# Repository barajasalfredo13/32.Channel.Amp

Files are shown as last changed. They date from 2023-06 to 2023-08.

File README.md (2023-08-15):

# 32.Channel.Amp
  
-----------------  
## Table of Contents
- 🔲 [Tile Boards]   
  - [Digi-Key Component List]
  - [Schematic]  
  - [Test Board]  
  - [Cell Board]  
- 🔲 [32 Cell Channel Receiver Board]  
  - [Cell Receiver Board]
  - [Cell Tester]
- 🔲 [Resources]  
  - [ Board Reference ]  
  - [ Amp Details ]  
  - [ Expected Connector ]  
  - [ Connections ]

----------------
## 🔲 ::: Tile Boards :::   
### : Component List :  
: Diodes :  
[ 1N4148W ](https://www.digikey.com/en/products/detail/smc-diode-solutions/1N4148W/6022450)  
[ BZT52H-A7V5-QX ](https://www.digikey.com/en/products/detail/nexperia-usa-inc/BZT52H-A7V5-QX/17295939)  
: Transistors :  
[ MMBT3904 ](https://www.digikey.com/en/products/detail/anbon-semiconductor-int-l-limited/MMBT3904/17284363)  
[ MMBT3906 ](https://www.digikey.com/en/products/detail/nte-electronics-inc/MMBT3906/11652283)  
: Capacitor :  
[ GRM188C81C106MA73J ](https://www.digikey.com/en/products/detail/murata-electronics/GRM188C81C106MA73J/4905316)  
: Resistors :  
[ RC0402JR-071KL ](https://www.digikey.com/en/products/detail/yageo/RC0402JR-071KL/726408)  
[ 311-4.7GRCT-ND ](https://www.digikey.com/en/products/detail/yageo/RC0603JR-074R7L/726784)  
: Cremat Holder :   
[ SMC-1-08-1-GT ](https://www.digikey.com/en/products/detail/adam-tech/SMC-1-08-1-GT/9830825)  
: DSUB Connector :  
[50 D-Sub](https://www.digikey.com/en/products/detail/harting/09665627811/4322749)  
[9 D-Sub](https://www.digikey.com/en/products/detail/te-connectivity-amp-connectors/2311765-1/7794751)  

### : Schematic :  
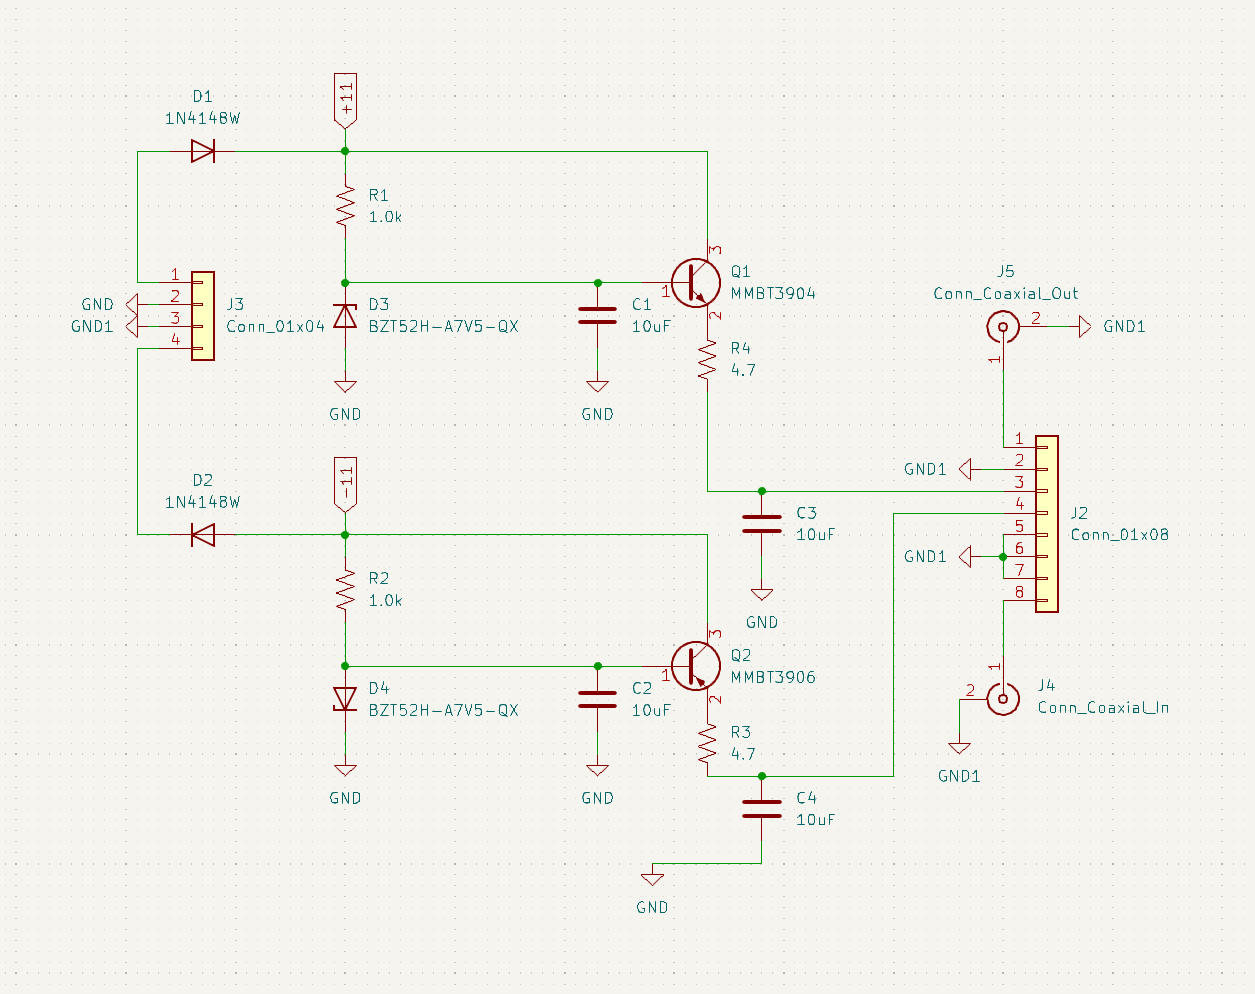
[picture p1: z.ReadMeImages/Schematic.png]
  
  
### :: Test Board ::  
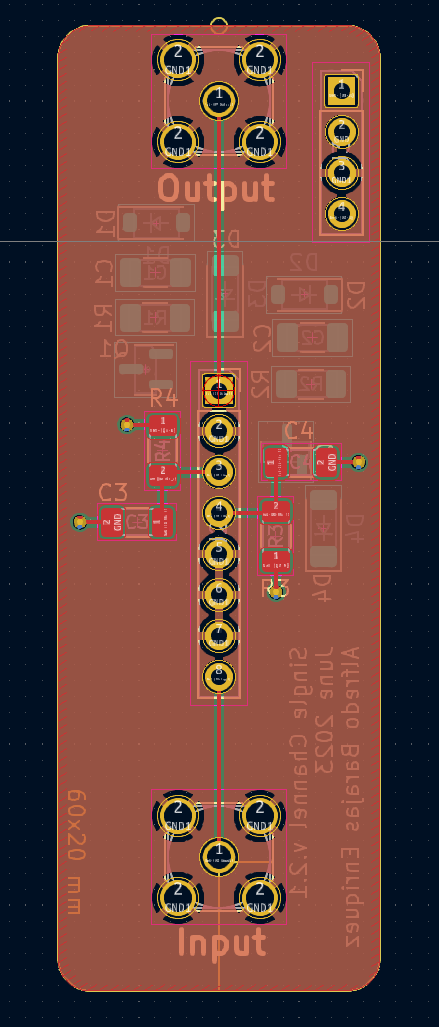
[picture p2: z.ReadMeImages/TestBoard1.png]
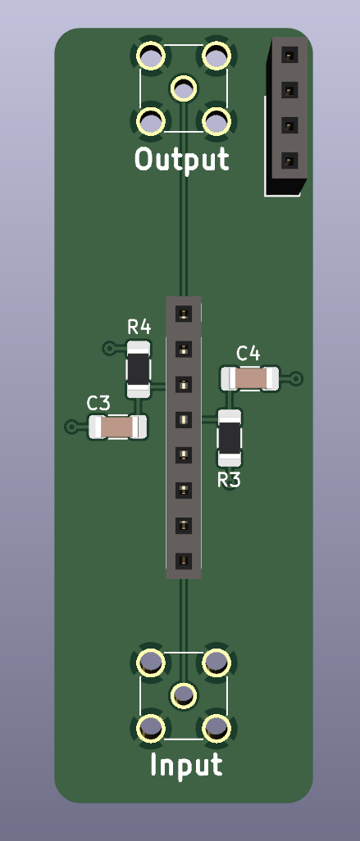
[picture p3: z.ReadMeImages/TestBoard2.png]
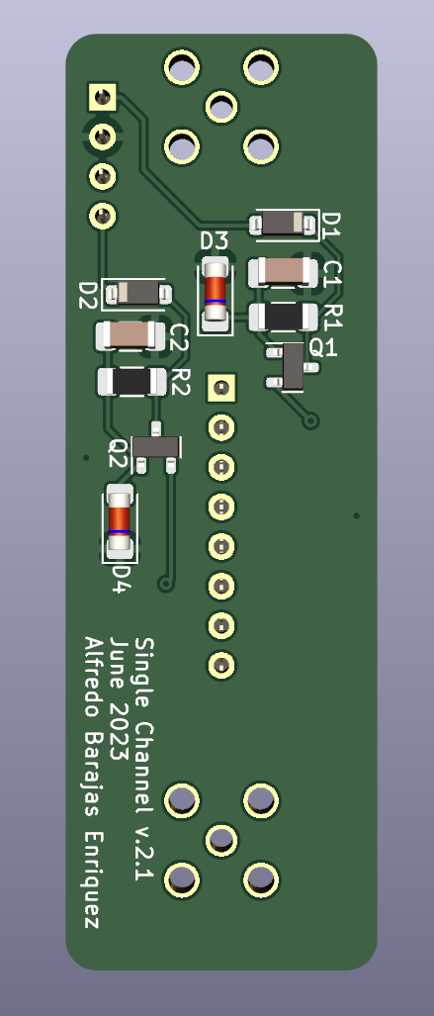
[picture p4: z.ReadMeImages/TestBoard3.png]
    
  
### :: Cell Board ::  
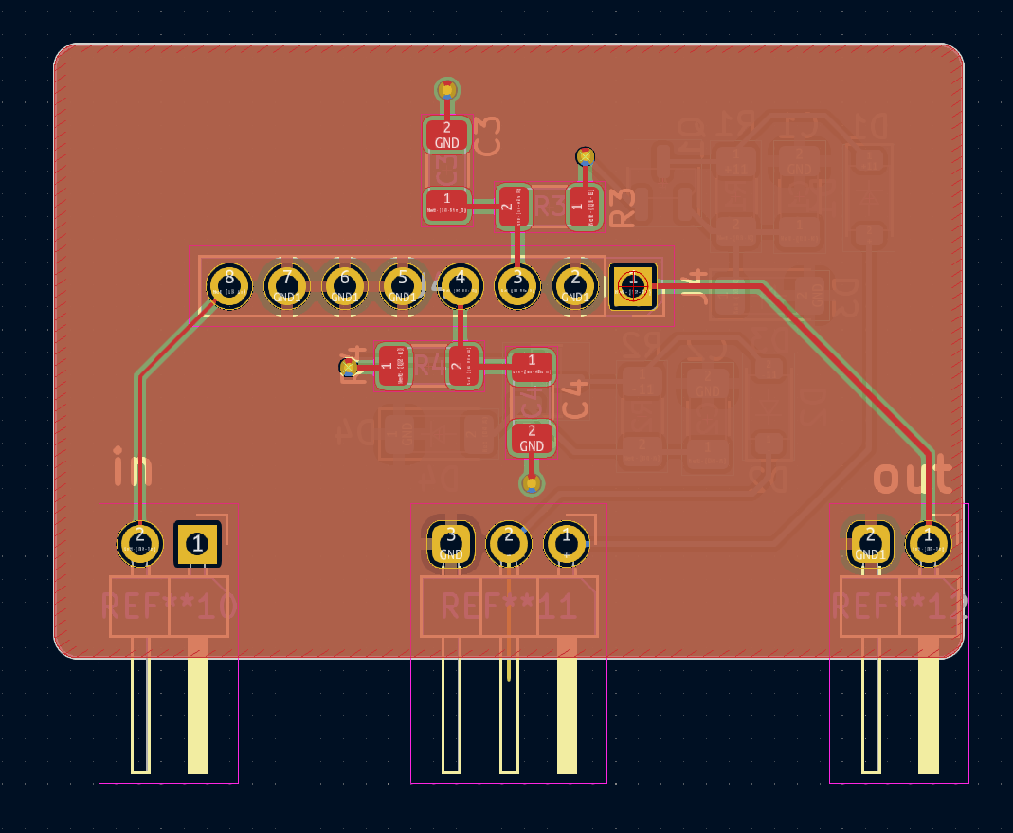
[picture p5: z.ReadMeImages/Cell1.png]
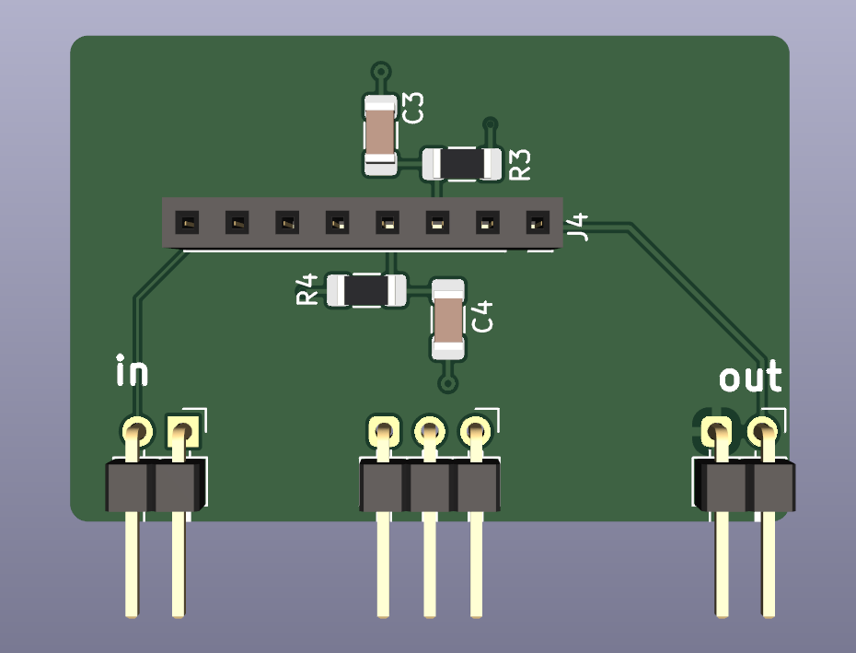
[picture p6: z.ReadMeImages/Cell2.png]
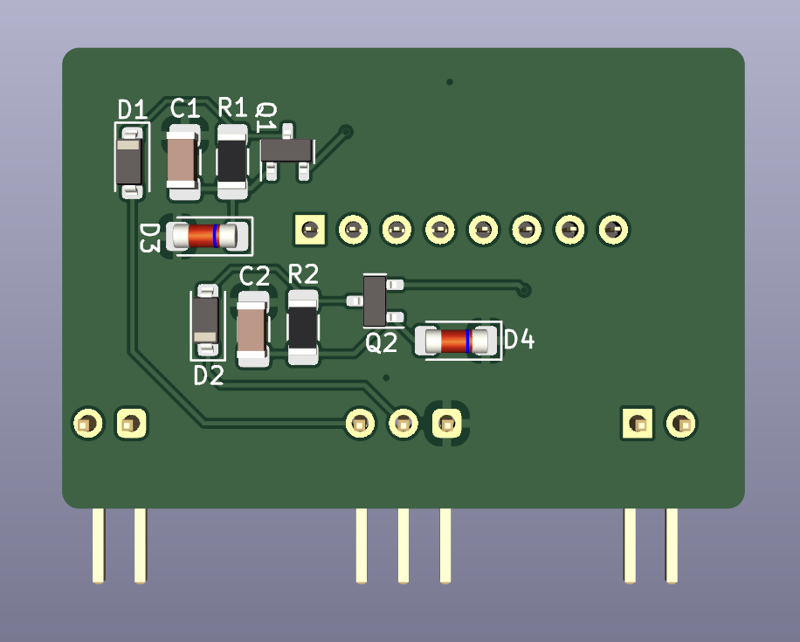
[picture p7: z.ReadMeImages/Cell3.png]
    
  
-------------------
## 🔲 :: 32 Cell Channel Receiver Board ::
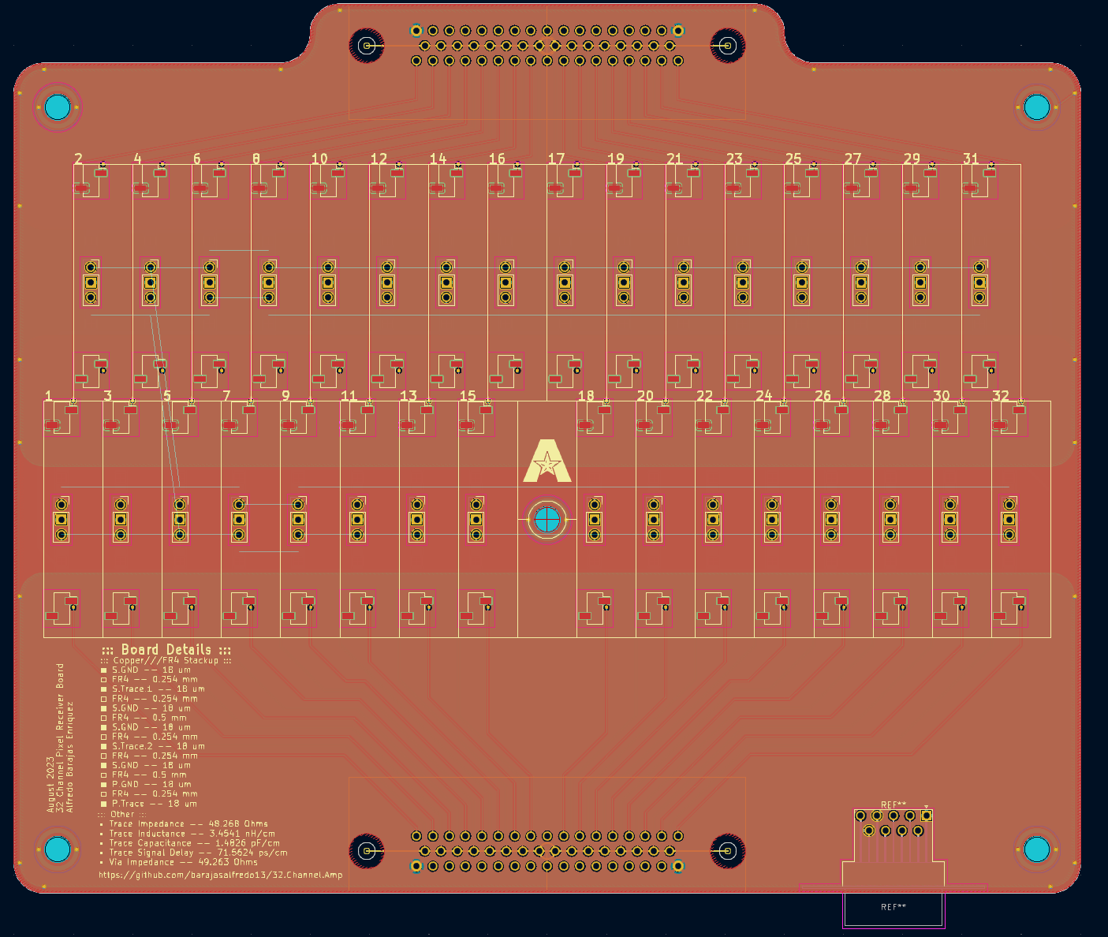
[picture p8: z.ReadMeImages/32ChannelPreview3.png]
  
  
### : Cell Receiver Board :  
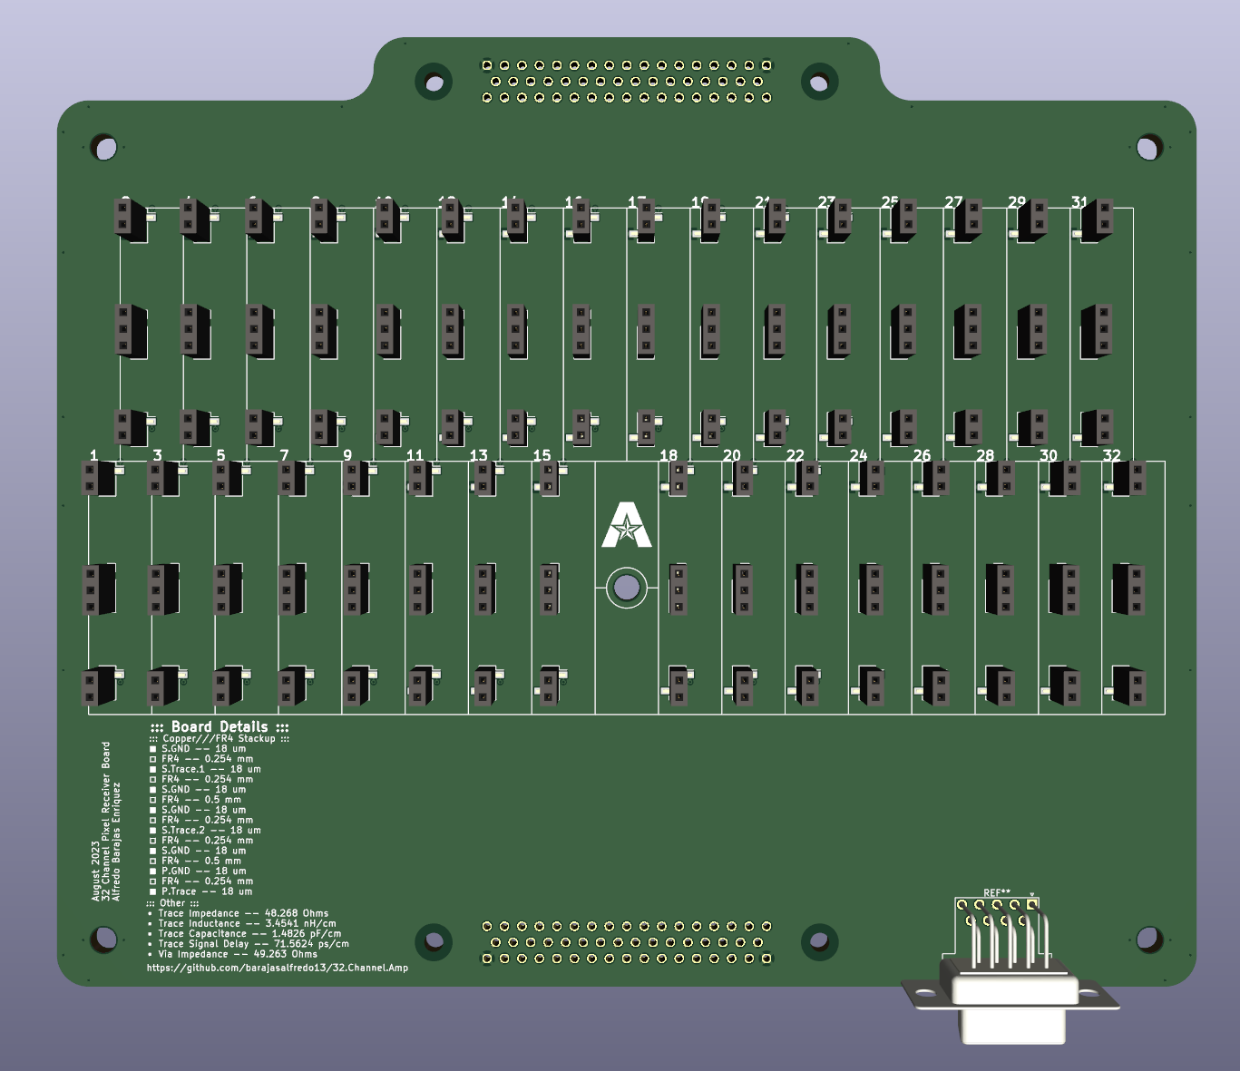
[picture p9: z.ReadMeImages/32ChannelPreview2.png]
   
   
### : Cell Tester :  
Cell Tester allows for easy and quick cell testing.  
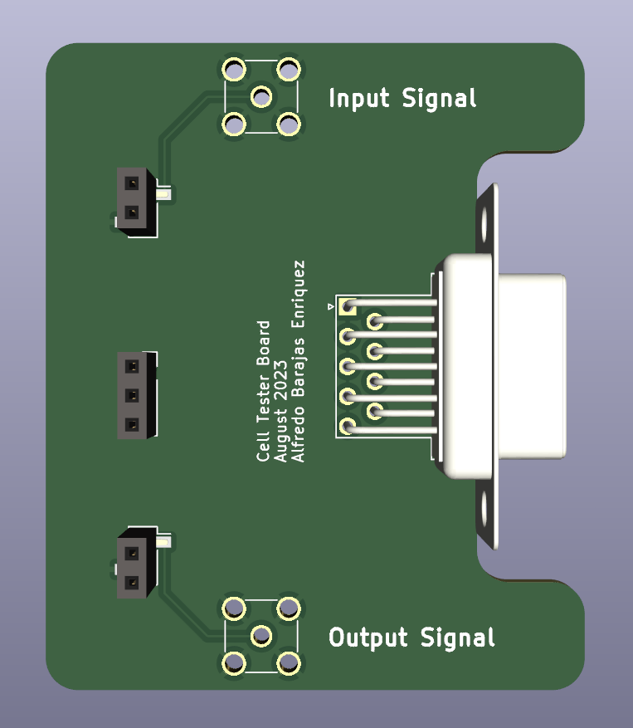
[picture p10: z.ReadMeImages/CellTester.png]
  
  
## 🔲 ::: Resources :::    
:: Board Referenced ::  
[CR-150-R5](https://www.cremat.com/CR-150-R5.pdf)  
  
:: Amp Details ::  
[CREMAT CR-11X](https://www.cremat.com/CR-110-R2.1.pdf)  
  
:: Expected Connector ::  
[IFDGG501056AX](https://www.lesker.com/feedthroughs/instrument-feedthroughs-mpdt-subd/part/ifdgg501056ax)  
  
### :: Connections ::  
###[SMC-1-08-1-GT](https://www.digikey.com/en/products/detail/adam-tech/SMC-1-08-1-GT/9830825)###  
: Drawing :  
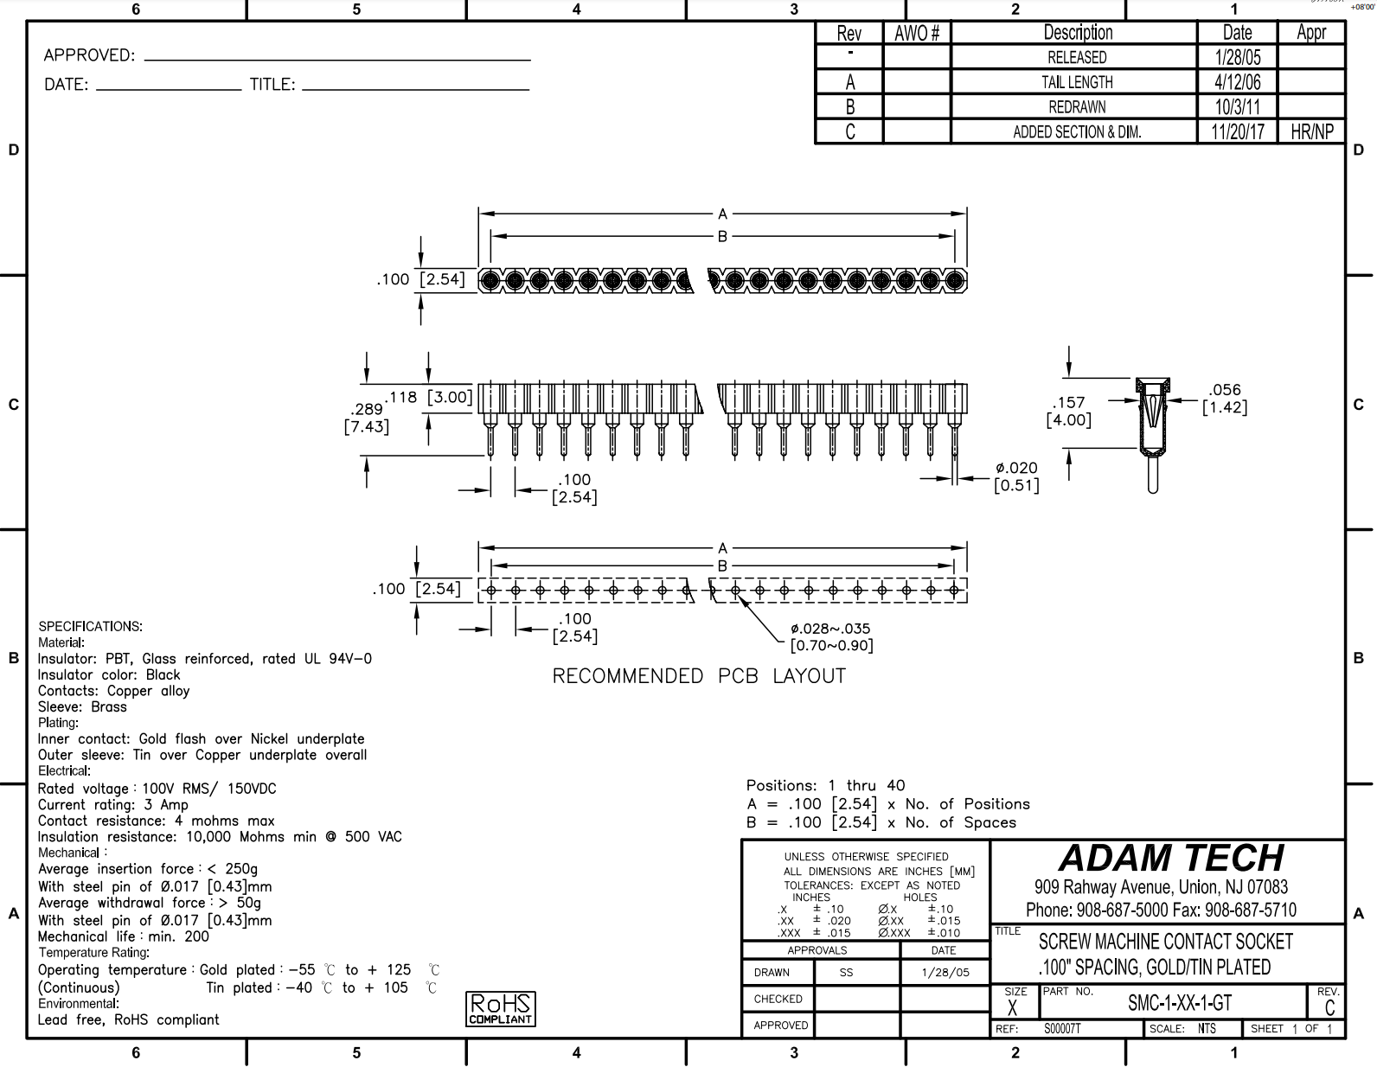
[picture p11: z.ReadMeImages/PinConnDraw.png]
  
: Generated Footprint :  
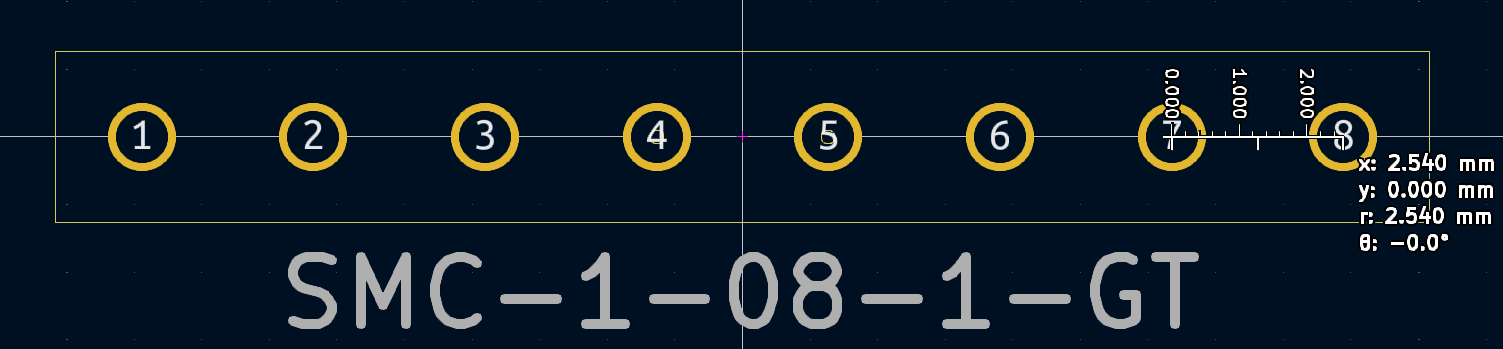
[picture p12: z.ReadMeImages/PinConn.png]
  
  
###[50 Position D-Sub Plug, Male Pins Connector](https://www.digikey.com/en/products/detail/harting/09665627811/4322749)###    
: Drawing :  
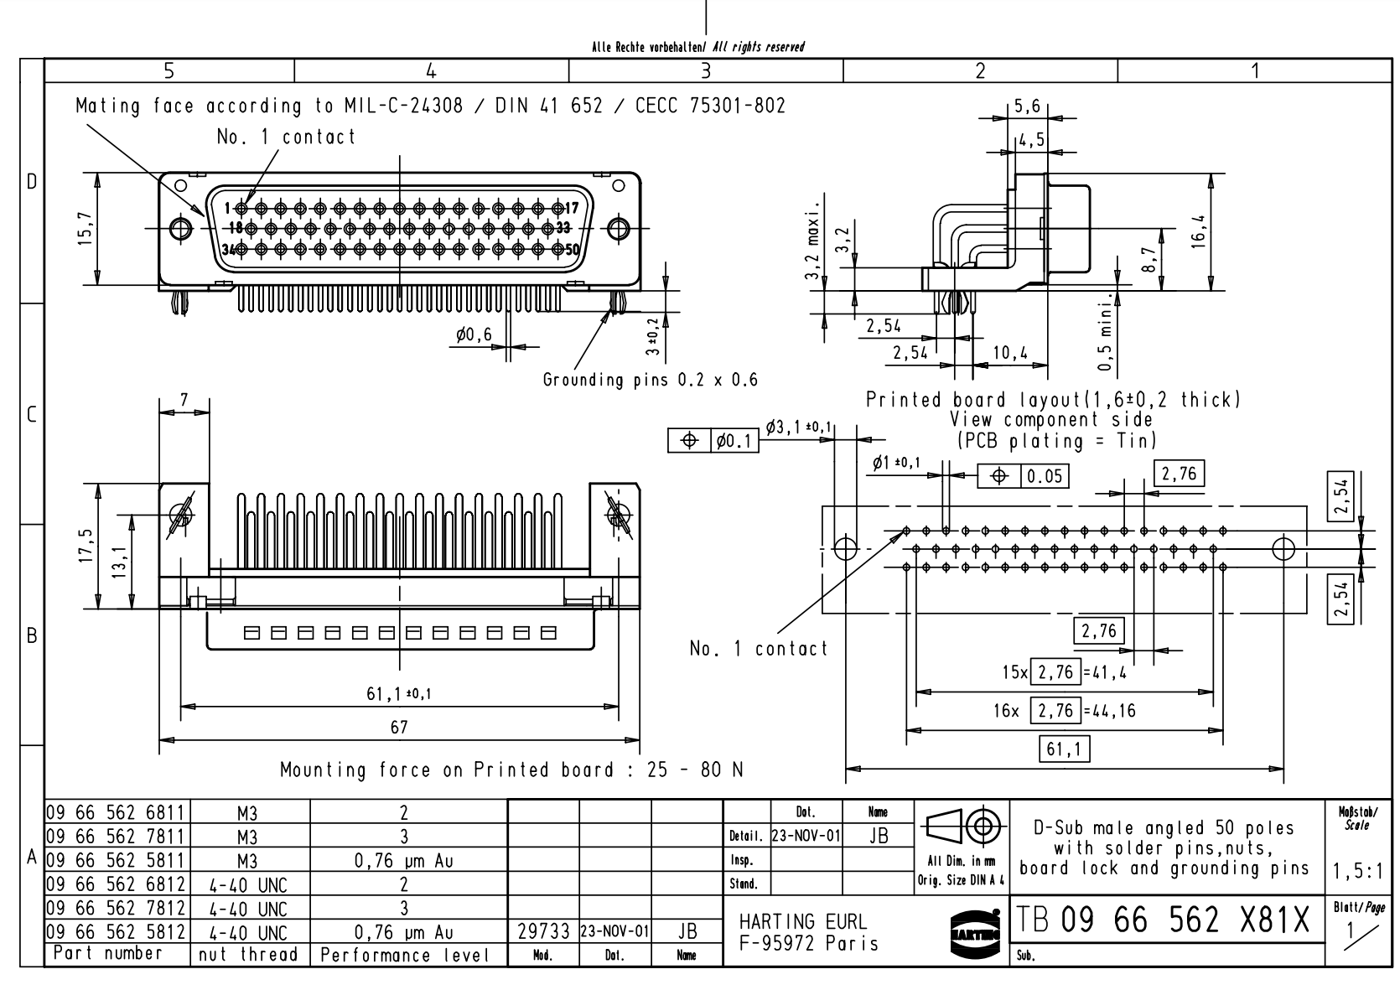
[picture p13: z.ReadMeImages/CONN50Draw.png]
  
: Generated Footprint :  
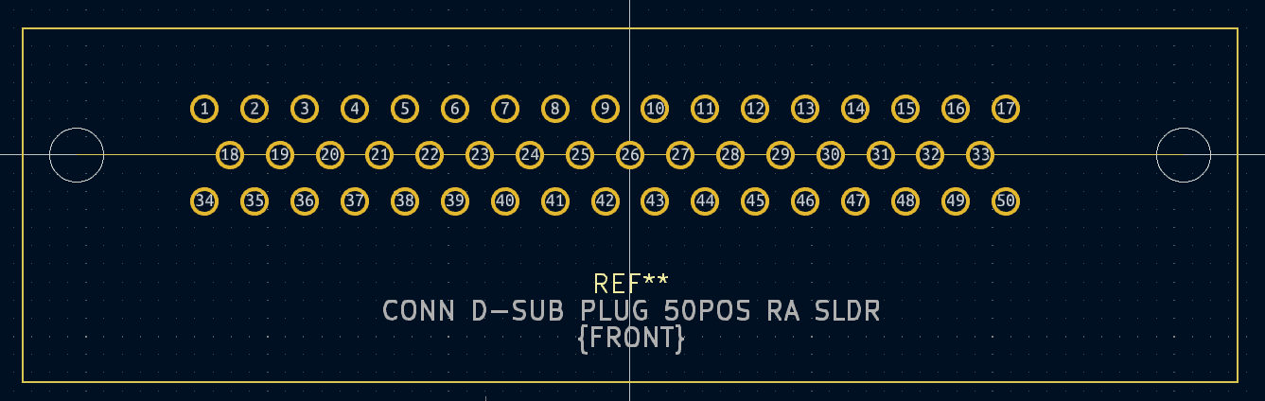
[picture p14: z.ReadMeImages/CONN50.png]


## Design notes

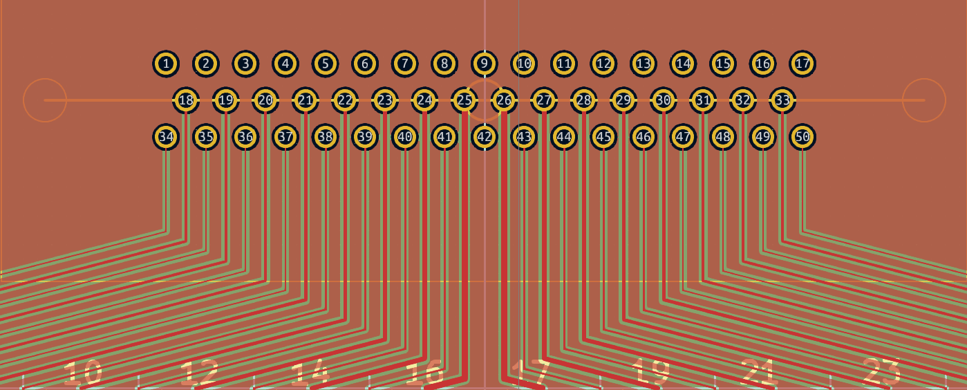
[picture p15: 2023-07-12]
z.ReadMeImages/CapacitanceDemo.png

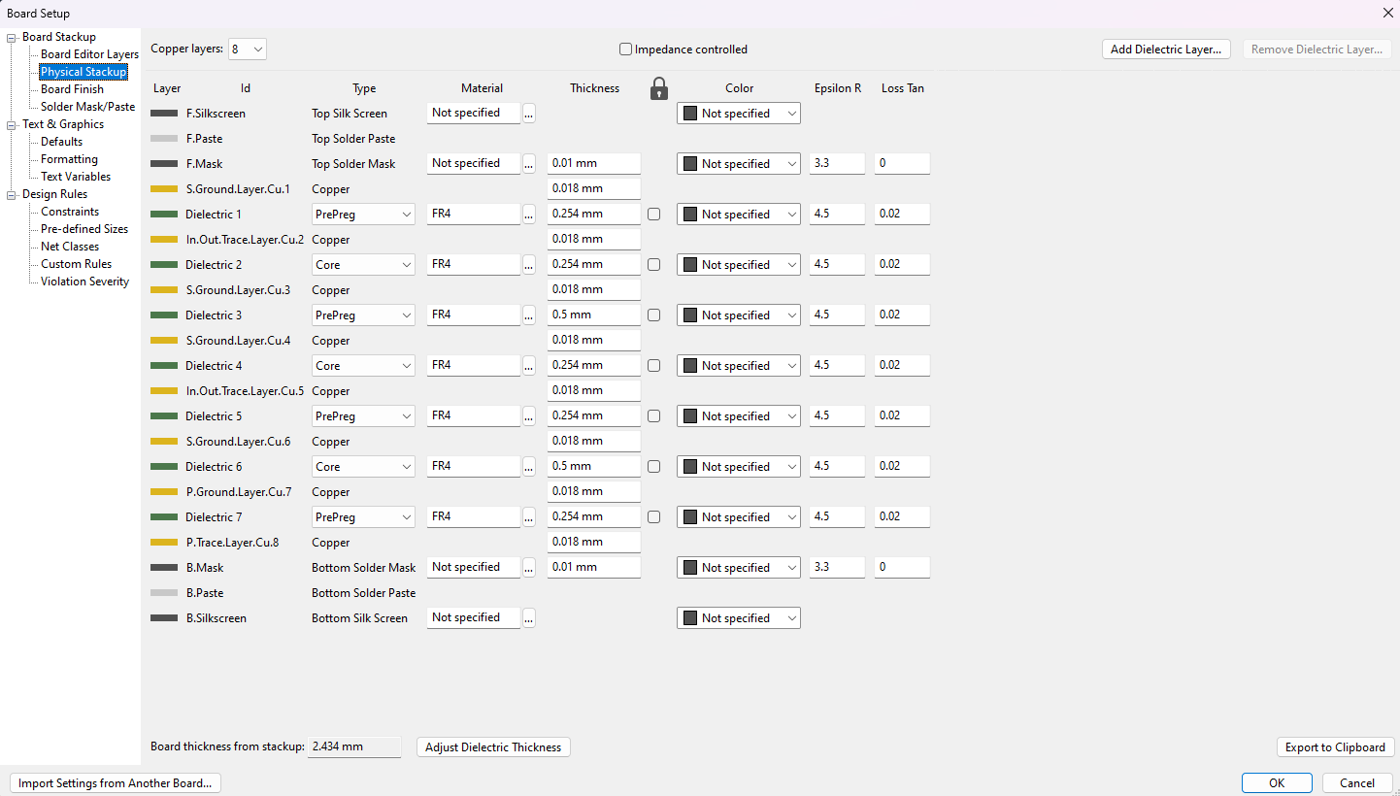
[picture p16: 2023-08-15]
z.ReadMeImages/BoardStackUp.png

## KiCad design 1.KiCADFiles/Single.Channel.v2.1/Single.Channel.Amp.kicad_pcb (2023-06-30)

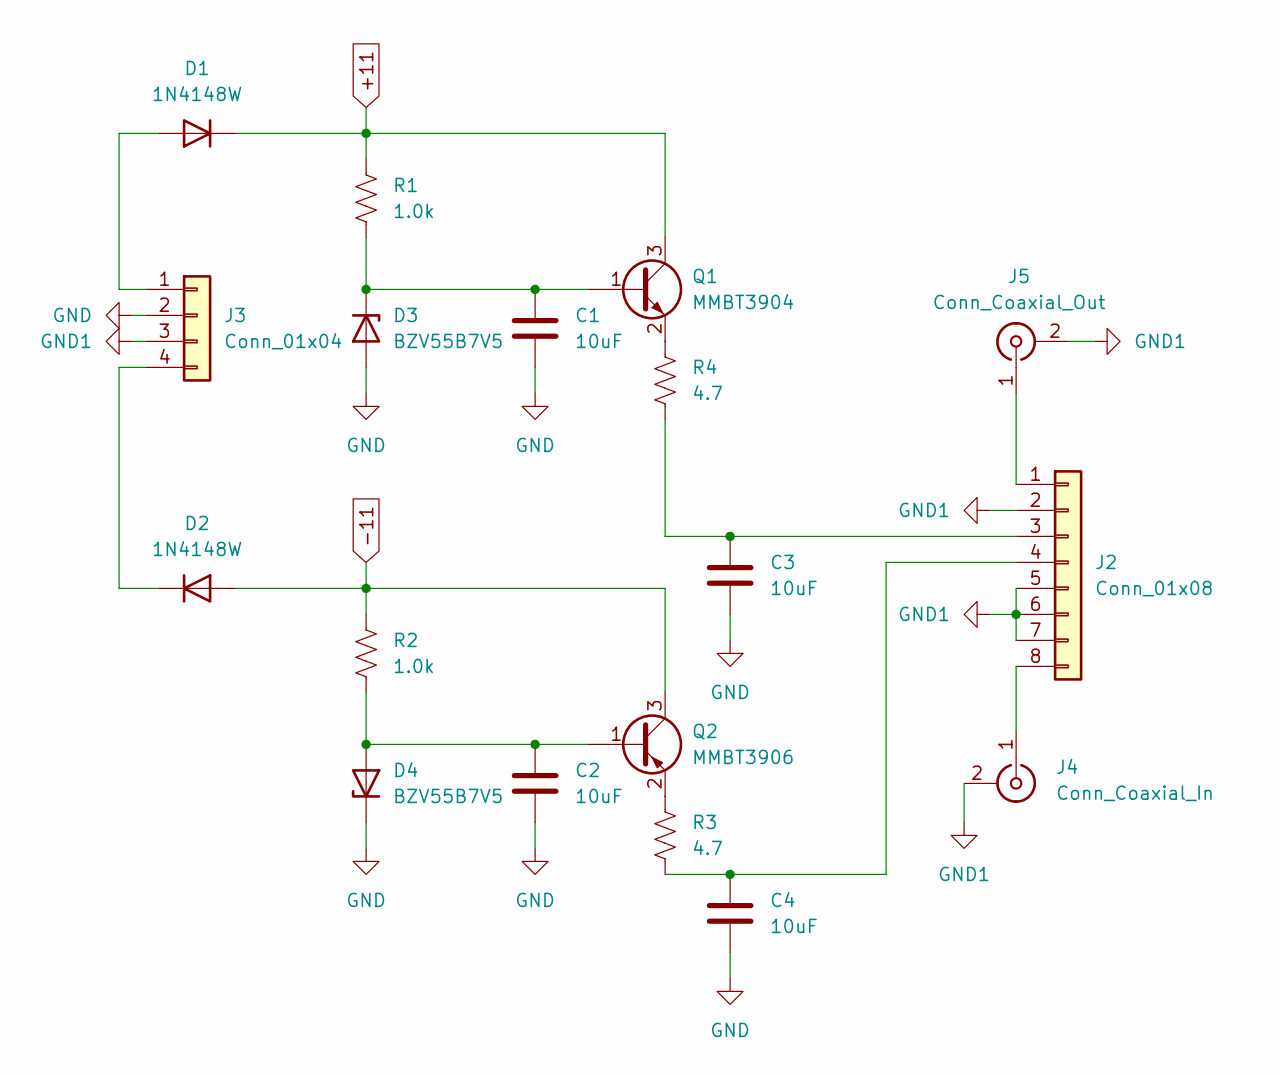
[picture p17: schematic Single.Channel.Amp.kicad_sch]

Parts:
C1, C2, C3, C4: 10uF; C_1206_3216Metric_Pad1.33x1.80mm_HandSolder
D1, D2: 1N4148W; D_SOD-123
D3, D4: BZV55B7V5; D_MiniMELF
J2: Conn_01x08; PinSocket_1x08_P2.54mm_Vertical
J3: Conn_01x04; PinSocket_1x04_P2.54mm_Vertical
J4: Conn_Coaxial_In; SMA_Amphenol_901-144_Vertical
J5: Conn_Coaxial_Out; SMA_Amphenol_901-144_Vertical
Q1: MMBT3904; SOT-23
Q2: MMBT3906; SOT-23
R1, R2: 1.0k; R_1206_3216Metric_Pad1.30x1.75mm_HandSolder
R3, R4: 4.7; R_1206_3216Metric_Pad1.30x1.75mm_HandSolder

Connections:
+11: D1.1 (K), Q1.3 (C), R1.1
-11: D2.2 (A), Q2.3 (C), R2.1
GND: C1.2, C2.2, C3.2, C4.2, D3.2 (A), D4.1 (K), J3.2
GND1: J2.2 (GND), J2.5, J2.6, J2.7, J3.3, J4.2 (Ext), J5.2 (Ext)
unnamed: D1.2 (A), J3.1
unnamed: D2.1 (K), J3.4
unnamed: C1.1, D3.1 (K), Q1.1 (B), R1.2
unnamed: C2.1, D4.2 (A), Q2.1 (B), R2.2
unnamed: J2.8 (Input), J4.1 (In)
unnamed: J2.1 (Output), J5.1 (In)
unnamed: C3.1, J2.3, R4.2
unnamed: C4.1, J2.4, R3.2
unnamed: Q1.2 (E), R4.1
unnamed: Q2.2 (E), R3.1

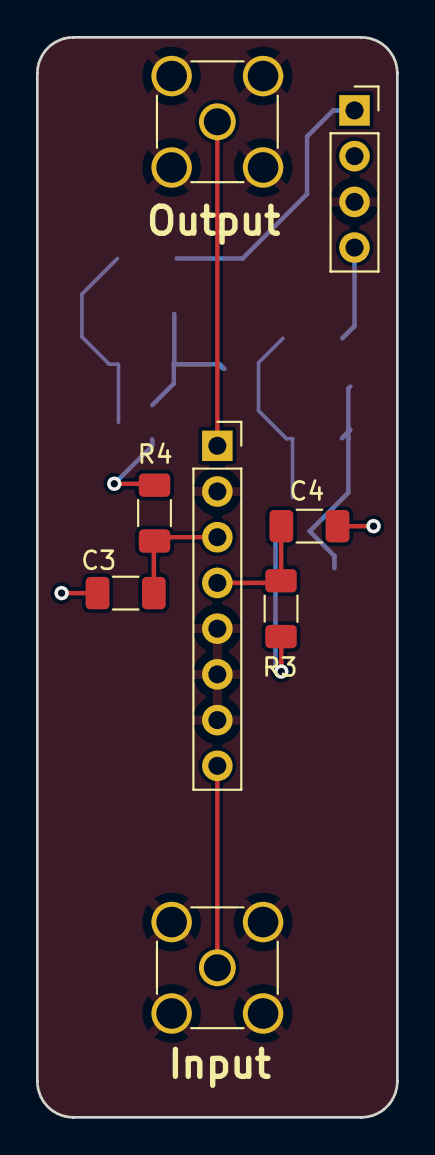
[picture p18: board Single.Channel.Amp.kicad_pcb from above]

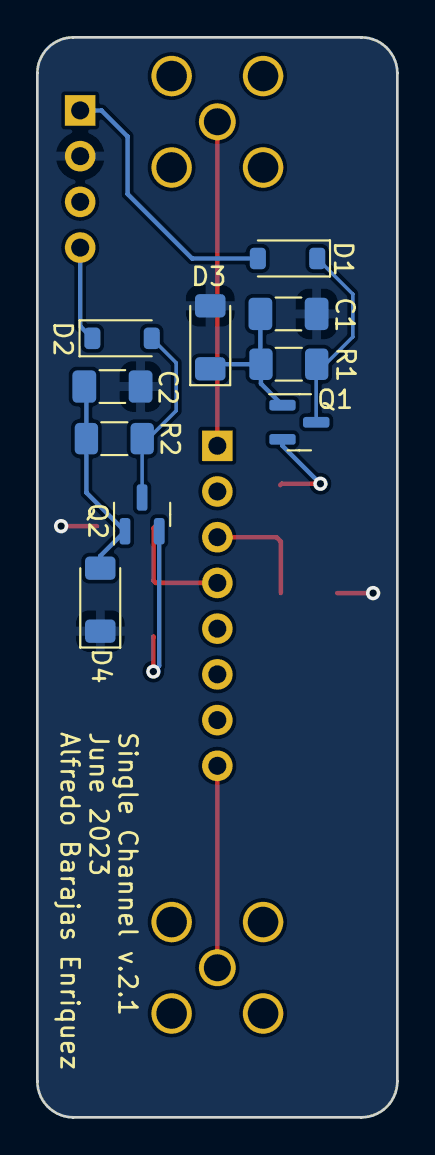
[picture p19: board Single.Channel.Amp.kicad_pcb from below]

Board: 4 copper layers, 20.0 x 60.0 mm, 18 parts (10 on the bottom side), 14 nets.

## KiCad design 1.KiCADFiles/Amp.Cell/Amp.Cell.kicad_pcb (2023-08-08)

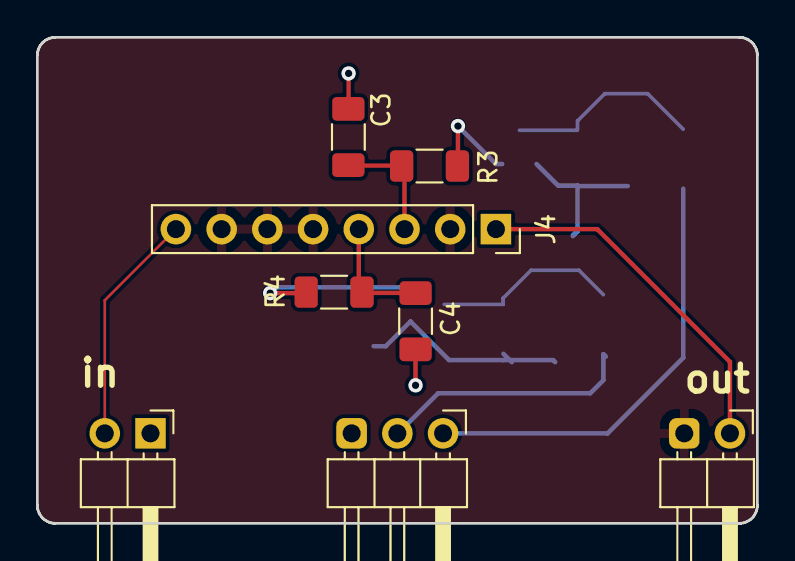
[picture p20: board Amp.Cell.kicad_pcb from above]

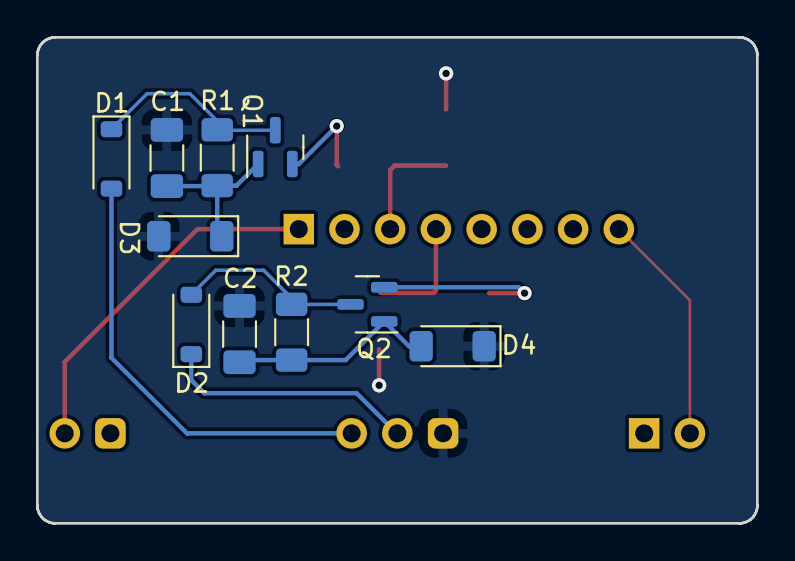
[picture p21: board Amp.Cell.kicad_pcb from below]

Board: 4 copper layers, 40.0 x 27.0 mm, 15 parts (10 on the bottom side), 10 nets.

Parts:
C1, C2, C3, C4: 10uF; C_1206_3216Metric_Pad1.33x1.80mm_HandSolder
D1, D2: 1N4148W; D_SOD-123
D3, D4: BZV55B7V5; D_MiniMELF
J4: Conn_01x08; PinSocket_1x08_P2.54mm_Vertical
Q1: MMBT3904; SOT-23
Q2: MMBT3906; SOT-23
R1, R2: 1.0k; R_1206_3216Metric_Pad1.30x1.75mm_HandSolder
R3, R4: 4.7; R_1206_3216Metric_Pad1.30x1.75mm_HandSolder

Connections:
+11: D1.1 (K), Q1.3 (C), R1.1
-11: D2.2 (A), Q2.3 (C), R2.1
GND: C1.2, C2.2, C3.2, C4.2, D3.2 (A), D4.1 (K)
GND1: J4.2 (GND), J4.5, J4.6, J4.7
unnamed: C1.1, D3.1 (K), Q1.1 (B), R1.2
unnamed: C2.1, D4.2 (A), Q2.1 (B), R2.2
unnamed: C3.1, J4.3, R3.2
unnamed: C4.1, J4.4, R4.2
unnamed: Q1.2 (E), R3.1
unnamed: Q2.2 (E), R4.1

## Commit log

2023-06-09 Added Skeleton Files
    [32.Channel.Amp.kicad_pcb, 32.Channel.Amp.kicad_sch]
2023-06-09 Updated README for materials and references used
2023-06-09 Minor Updates
    [32.Channel.Amp.kicad_pcb]
2023-06-09 Created Footprints for Connector Components
2023-06-09 Updated Readme to Showcase Connectors
2023-06-10 Skeleton Layout Created
    [32.Channel.Amp.kicad_pcb]
2023-06-12 Added DB9 and Created a General Layout
    [32.Channel.Amp.kicad_pcb]
2023-06-13 Updated Files
    [32.Channel.Amp.kicad_pcb]
2023-06-13 Added +V and -V regulators
    [32.Channel.Amp.kicad_pcb, 32.Channel.Amp.kicad_sch]
2023-06-13 Added Power Regulator, RC Filtering, and 32 Channel
    [32.Channel.Amp.kicad_pcb]
2023-06-20 Added Single Channel
    [32.Channel.Amp.kicad_pcb, Single.Channel.Amp.kicad_pcb]
2023-06-20 Small Adjustments to Single Channel
    [Single.Channel.Amp.kicad_pcb]
2023-06-20 Minor Changes
    [Single.Channel.Amp.kicad_pcb]
2023-06-20 Generated Gerber Files
    [Single.Channel.Amp-B_Cu.gbr, Single.Channel.Amp-B_Mask.gbr, Single.Channel.Amp-B_Paste.gbr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]
2023-06-22 Updated Single Channel Test Board, Generated Gerber and Plot Files
    [Single.Channel.Amp-B_Cu.gbr, Single.Channel.Amp-B_Mask.gbr, Single.Channel.Amp-B_Paste.gbr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]
2023-06-23 Updated Single Channel board as a Tile
    [Single.Channel.Amp-B_Cu.gbr, Single.Channel.Amp-B_Mask.gbr, Single.Channel.Amp-B_Paste.gbr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]
2023-06-28 Template Format Created for 32 Channel Amp
    [32.Channel.Amp.kicad_pcb, Single.Channel.Amp.kicad_pcb]
2023-06-30 Created 16 Channel Box
    [32.Channel.Amp.kicad_sch]
2023-06-30 Updated Voltage Reference Points
    [Single.Channel.Amp-B_Cu.gbr, Single.Channel.Amp-B_Mask.gbr, Single.Channel.Amp-B_Paste.gbr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]
2023-07-11 Updated 32 Channel Format, Included Chip Board
    [32.Channel.Amp.kicad_pcb, 32.Channel.Amp.kicad_sch]
2023-07-11 Created two 32 Channel Boards. Adjusted traces for capacitance
    [32.Channel.Amp.Tight.Fit.kicad_pcb, 32.Channel.Amp.kicad_pcb]
2023-07-11 Uploaded Trace Width Calculator
    [Trace.Calculator.ods]
2023-07-12 Added Amp Cell for 32 Channel Board
    [32.Channel.Amp.Tight.Fit.kicad_pcb, 32.Channel.Amp.kicad_pcb, Amp.Cell.kicad_pcb]
2023-07-12 Added Screenshots and Documentation Files
    [32.Channel.Amp.kicad_pcb]
2023-07-13 Updated Preview Files, Added Cell Pin Blueprint, Created Cell Tester
    [32.Channel.Amp.kicad_pcb]
2023-07-13 Updated PCB Descriptions
2023-07-13 Cleaned Files
    [32.Channel.Amp.Tight.Fit.kicad_pcb, 32.Channel.Amp.kicad_sch, Amp.Cell.kicad_pcb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]
2023-07-14 Small Changes to Receiver Board
    [Receiver.Board.kicad_pcb]
2023-07-14 Started signal trace lines
    [Receiver.Board.kicad_pcb, Receiver.Board.kicad_sch]
2023-07-16 Began adding signal traces, added cell holders
    [Amp.Cell.kicad_pcb, Receiver.Board.kicad_pcb]
2023-07-16 Fixed cell board orientation, routed power lines, fixed wire capacitance with new lengths, updated excel sheet to include all traces
    [Receiver.Board.kicad_pcb, Trace.Calculator.ods]
2023-07-17 Minor Fixes, Updated Excel Sheet to contain approx surface area
    [Receiver.Board.kicad_pcb, Trace.Calculator.ods]
2023-07-17 Minor Graphic Changes
    [Receiver.Board.kicad_pcb]
2023-07-17 Minor Adjustments
    [Trace.Calculator.ods]
2023-07-17 Added Repository Link to Receiver Board
    [Receiver.Board.kicad_pcb]
2023-07-21 Added 4/8/16 Layer boards
    [4.Layer.Receiver.Board.kicad_pcb, Receiver.Board.kicad_pcb, Receiver.Board.kicad_sch]
2023-07-23 Added board variants, minor fixes
2023-07-26 Started Sketch Designs with Multiple Layer Versions
    [10.Layer.ReceiverBoard.kicad_pcb, 8.Layer.ReceiverBoard.kicad_pcb, 8.Layer.ReceiverBoard.kicad_sch]
2023-07-26 Added all tools in a separate folder
    [Trace.Calculator.ods]
2023-07-30 Updated Receiver Board
    [10.Layer.ReceiverBoard.kicad_pcb, 12.Layer.ReceiverBoard.kicad_pcb, 12.Layer.ReceiverBoard.kicad_sch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]
2023-07-31 Added Base
    [12.Layer.ReceiverBoard.kicad_pcb]
2023-08-01 Mnimized Board Stack, Fixed Input Impedance
    [12.Layer.ReceiverBoard.kicad_pcb, 12.Layer.ReceiverBoard.kicad_sch, 4.Layer.Receiver.Board.kicad_pcb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]
2023-08-02 Major Design Changes
    [8.Layer.Receiver.No.Wrap.kicad_pcb]
2023-08-14 Updated schematic with new Zener Component, updated componenet list
    [Single.Channel.Amp.kicad_sch]
2023-08-15 Added Tester Board
    [Cell.Tester.kicad_pcb, Cell.Tester.kicad_sch]
2024-05-20 Updated Schematic Diagram for Single Channel Board
    [Single.Channel.Amp.kicad_sch]
